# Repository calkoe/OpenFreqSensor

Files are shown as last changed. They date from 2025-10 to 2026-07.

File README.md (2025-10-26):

# ⚡ OpenFrequencySensor - Open Source Power Grid Frequency Monitor

A low-cost, high-precision power grid frequency monitoring solution for the European power grid. Monitor grid stability with ±0.002Hz precision and get instant alerts for frequency deviations.

#### Features

- 📊 Real-time frequency monitoring (±0.002Hz precision)
- 🔔 Local alerts via LCD display and buzzer
- 📡 MQTT data transmission
- 📱 20x4 LCD interface with button controls
- 🔋 Offline operation capability
- 📦 3D-printable case included

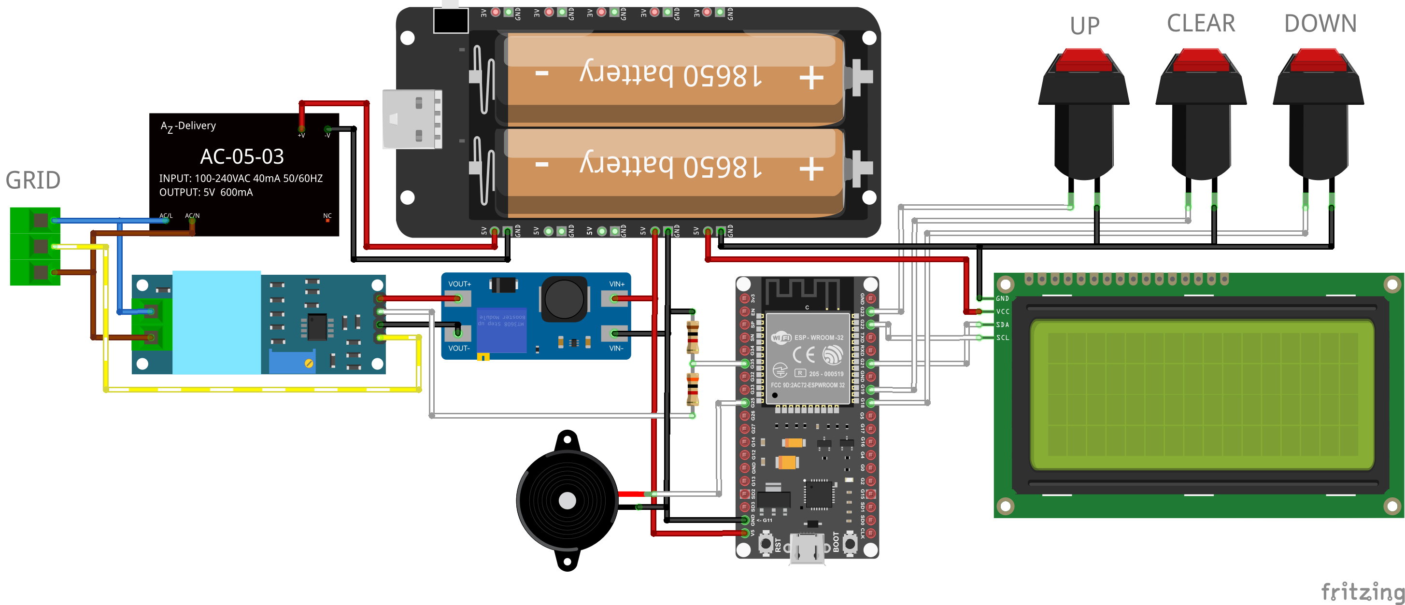
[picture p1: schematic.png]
Schematic


## Why Monitor Grid Frequency?

Frequency is the heartbeat of the electrical grid - it reflects the instantaneous balance between electricity generation and consumption across the entire Continental European network. When this balance shifts, frequency changes reveal:

- **Supply-Demand Imbalances**: Frequency drops when demand exceeds generation, rises when generation exceeds demand

Every frequency change tells a story about grid operations:

- **Slow Drifts (minutes)**: Indicate systematic generation-load imbalances, economic dispatch changes
- **Fast Changes (seconds)**: Reveal sudden events like generator trips, large load connections/disconnections
- **Oscillations**: Show control system interactions, potential stability issues
- **Rate of Change**: Indicates how rapidly the system is losing or gaining energy

By monitoring frequency, you gain insight into:

- **Early Warning System**: Detect grid disturbances before they escalate to blackouts
- **Load-Generation Balance**: Understand real-time supply and demand dynamics

Critical Thresholds (ENTSO-E Standards)

| Threshold | Value | Description |
| --- | --- | --- |
| Standard Frequency Range | 49.95 - 50.05 Hz | Normal operating range |
| Alert Range | 49.8 - 50.2 Hz | Deviation monitoring required |
| Level 1 Emergency | 49.2 - 50.8 Hz | Emergency state |
| Level 2 Emergency | 47.5 - 51.5 Hz | Blackout risk |
| Rate of Change (RoCoF) | > ±0.5 Hz/s | Dynamic stability threshold |

Source: ENTSO-E Operation Handbook, Policy 1: Load-Frequency Control and Performance, Section A-S1: Standard Frequency Range Parameters. These are the official thresholds for the Continental Europe Synchronous Area.

## Live Demo and Data Analysis

View real-time frequency data from this sensor: [Live Dashboard](https://grafana.fastalert.nrw/public-dashboards/0828674a5dd54280aab2e0723ffaba71?orgId=3&refresh=1s)

For comprehensive grid analysis and historical data, visit [Energy-Charts](https://www.energy-charts.info/index.html?l=de&c=DE), maintained by Fraunhofer ISE.

## Getting Started

#### Hardware Requirements

- ESP32 development board [Link](https://www.az-delivery.de/en/products/esp32-developmentboard)
- 20x4 LCD display (I2C) [Link](https://www.az-delivery.de/en/products/hd44780-2004-lcd-display-bundle-4x20-zeichen-mit-i2c-schnittstelle)
- Push buttons (3x) [Link](https://www.amazon.de/-/en/pieces-momentary-pressure-lockless-dashboard/dp/B0DJNWWRSL)
- Buzzer [Link](https://www.az-delivery.de/products/buzzer-modul-passiv)
- ZMPT101B Active Single Phase Voltage Transformer [LINK](https://www.amazon.de/ANGEEK-ZMPT101B-Voltage-Transformer-Arduino/dp/B07ZDJS7CD)
- 5V USV Module [LINK](https://de.aliexpress.com/item/1005009864874228.html)
- HDR-15 Power Supply [LINK](https://www.amazon.de/-/en/Amazon-Parent-MeanWell-Series-HDR-15/dp/B06XWQSJGW)

##### 3D Printable Case

The device housing consists of three parts that can be 3D printed:

- [Part 1 (Base)](Part1.stl)
- [Part 2 (Display Frame)](Part2.stl)
- [Part 3 (Cover)](Part3.stl)

Print Settings:

- Material: PETG or ABS recommended (better heat resistance than PLA)
- Layer Height: 0.2mm
- Infill: 25%

#### Software

1. **Hardware Setup**

   - Follow the provided schematic
   - Print the case using provided STL file
   - Connect components according to pin configuration:
     ```
     ADC Input: GPIO34
     LCD: SDA -> GPIO21, SCL -> GPIO22
     Buttons: Up -> GPIO23, Down -> GPIO19, Mute -> GPIO18
     Buzzer: GPIO25
     ```

2. **Software Setup**

   ```bash
   # Clone the repository
   git clone https://github.com/calkoe/OpenFreqSensor

   # Install PlatformIO
   # Open project in PlatformIO
   # Configure wifi settings in config.h
   # Build and upload
   ```

3. **Configuration**

   - Copy `include/config.template.h` to `include/config.h`
   - Edit `config.h` with your settings:

     ```cpp
     // Network settings
     #define WIFI_SSID "your_ssid"
     #define WIFI_PASSWORD "your_password"
     #define MQTT_SERVER "your_mqtt_server"
     #define MQTT_USERNAME "your_username"
     #define MQTT_PASSWORD "your_password"

     // Device identification
     #define SENSOR_ID "freqsensor/your_id"
     ```

   - The template file contains all available configuration options
   - `config.h` is ignored by git to keep your private settings secure

#### MQTT Data Format

The sensor publishes JSON messages with the following structure:

```json
{
  "sensorId": "freqsensor/koecher1", // Unique sensor identifier
  "time": 1761407894423, // UNIX timestamp in milliseconds
  "freq": 49.964, // Current grid frequency in Hz
  "amp": 167844.8, // Signal amplitude (ADC units)
  "quality": 0.012, // Measurement quality (lower is better)
  "alert": false, // Whether frequency exceeds thresholds
  "alertType": "none", // Type of alert if triggered
  "deviation": 0.036, // Deviation from 50 Hz
  "ramp": 0.002990723, // Rate of change in Hz/s
  "analyzingDelay": 250, // Processing time in ms
  "freeHeap": 111228, // Available ESP32 memory in bytes
  "heapUsage": 65.4, // Memory usage percentage
  "cpuFreq": 240, // CPU frequency in MHz
  "wifiRSSI": -60 // WiFi signal strength in dBm
}
```

#### Technical Details

- Sampling Rate: 512 Hz
- FFT Analysis Size: 512 samples
- Gaussian interpolation for high precision
- Ring buffer size: 4096 samples
- Analysis interval: 250ms

## Example Build

#### Completed Device

- Assembled with ESP32 and components
- 3D printed case
- LCD display showing real-time frequency readings

#### Testing Results

- Frequency accuracy: ±0.002Hz verified against reference meter
- Response time: <250ms for frequency changes
- MQTT connectivity: Stable data transmission
- Battery backup: 4+ hours operation during power outages

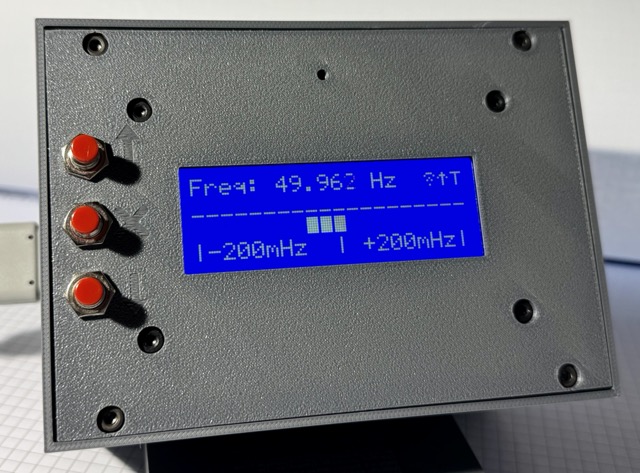
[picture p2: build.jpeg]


## Contributing

Pull requests are welcome. For major changes, please open an issue first to discuss what you would like to change.

## License

[MIT](LICENSE)

## Disclaimer and Safety Warning ⚠️

#### Legal Disclaimer

This project is provided "AS IS", without warranty of any kind, express or implied. By using this project, you agree that:

- The authors and contributors are NOT LIABLE for any damages or injuries arising from the use of this project
- This project is for EDUCATIONAL AND RESEARCH PURPOSES ONLY
- Any use of this project is AT YOUR OWN RISK
- The accuracy and reliability of measurements cannot be guaranteed
- This is NOT a certified measurement device

#### Safety Warning ⚡

This device:

- Connects to LETHAL MAINS VOLTAGE (230V AC)
- Should ONLY be built and installed by QUALIFIED PERSONNEL
- Requires proper electrical isolation and safety measures
- Must be properly enclosed in an insulated case
- Should never be operated without proper safety barriers

DO NOT attempt to build or use this device unless you:

- Are a qualified electrician or electrical engineer
- Fully understand the risks of working with mains voltage
- Know how to properly isolate high-voltage circuits
- Can implement proper safety measures

IMPROPER USE CAN RESULT IN:

- Electric shock
- Death
- Fire
- Property damage

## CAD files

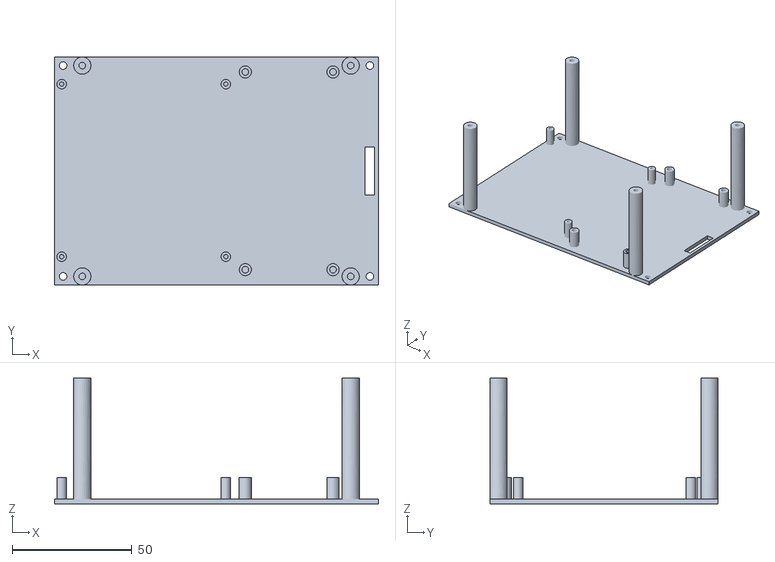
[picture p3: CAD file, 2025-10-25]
Part2.stl
135.2 x 95.2 x 52.5

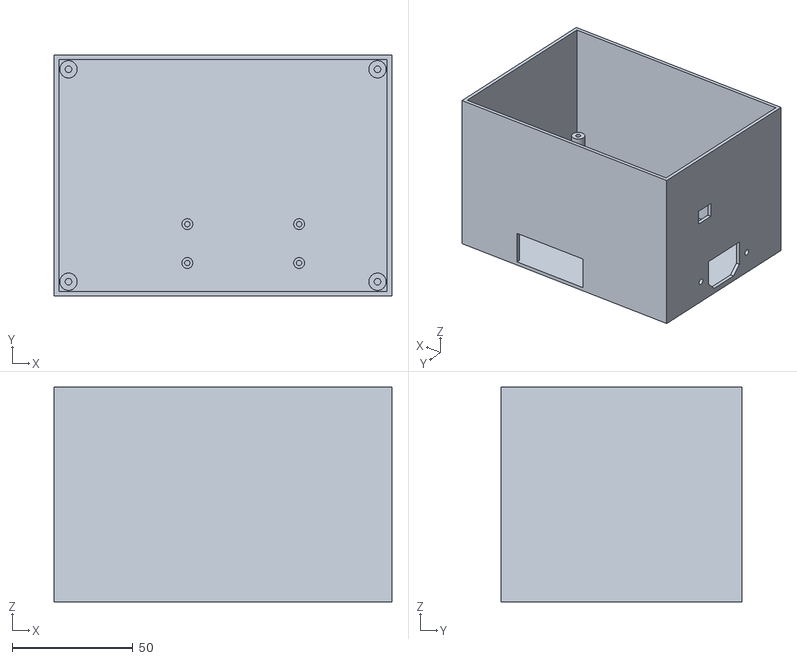
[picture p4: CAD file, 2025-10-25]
Part1.stl
140.0 x 100.0 x 89.0

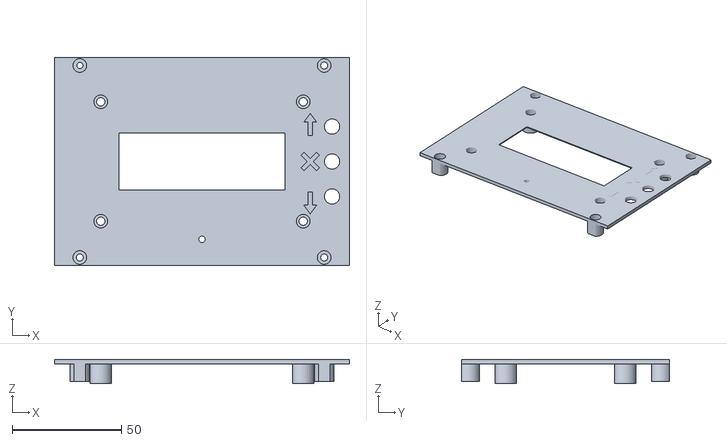
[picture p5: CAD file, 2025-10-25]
Part3.stl
135.2 x 95.2 x 11.0

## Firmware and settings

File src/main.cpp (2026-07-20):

#include "main.h"
#include <esp_task_wdt.h>

// Global variables initialization
hw_timer_t *timer = NULL;
Networking *networking = nullptr;
FrequencyAnalyzer *analyzer = nullptr;
FrequencyInterpreter *interpreter = nullptr;
FrequencyTransmitter *transmitter = nullptr;
DisplayHandler *display = nullptr;

// ISR must stay minimal: analogRead() & friends are not ISR-safe (flash
// resident, take locks) and crash/hang when WiFi does flash writes.
// The actual sampling happens in the analyzer's high-priority task.
void IRAM_ATTR onTimer(){
    analyzer->notifySampleFromISR();
}

void setup_timer(){

    // Configure timer for stable 512Hz sampling with larger prescaler
    uint32_t apb_freq = getApbFrequency();
    uint32_t prescaler = 2;
    uint32_t timer_divider = apb_freq / (prescaler * SAMPLING_FREQUENCY);

    timer = timerBegin(0, prescaler, true);
    timerAttachInterrupt(timer, &onTimer, true);
    timerAlarmWrite(timer, timer_divider, true);
    timerAlarmEnable(timer);

    Serial.printf("APB Freq: %lu Hz, Timer Divider: %lu, Actual sampling rate: %.2f Hz\n",
                  apb_freq, timer_divider, (float)apb_freq / (prescaler * timer_divider));

}

void setup(){

    // Set CPU frequency
    setCpuFrequencyMhz(CPU_FREQUENCY_MHZ);
    Serial.begin(115200);

    // Watchdog: reboot instead of hanging forever if loop() ever stalls
    // (e.g. network stack wedged). Timeout must exceed the worst-case
    // blocking TLS connect (2 x NET_TIMEOUT_S).
    esp_task_wdt_init(WDT_TIMEOUT_S, true);
    esp_task_wdt_add(NULL);

    // Initialize Display
    display = new DisplayHandler();
    display->begin();

    // Initialize networking
    networking = new Networking();
    networking->begin();

    // Initialize frequency analysis components
    analyzer = new FrequencyAnalyzer();
    interpreter = new FrequencyInterpreter();
    transmitter = new FrequencyTransmitter(networking->getMqttClient());

    // Start sampling task, then the timer that triggers it
    pinMode(ADC_PIN,INPUT);
    analyzer->beginSampling();
    setup_timer();

}

void loop(){

      // Feed the watchdog
      esp_task_wdt_reset();

      // Analyze Data
      FrequencyAnalysis frequencyAnalysis{0};
      if(analyzer->getNextSliceAnalysis(&frequencyAnalysis)){
        FrequencyAlert alert = interpreter->interpret(frequencyAnalysis);
        display->updateAnalysis(frequencyAnalysis);
        if(alert.valid){

            // Update display and handle alerts
            if (alert.hasAlert) display->addAlert(alert);

            // Transmit the results via MQTT
            transmitter->transmit(alert);

        }

        // Debug information
        Serial.print("Freq: ");
        Serial.print(frequencyAnalysis.frequency, 3);
        Serial.print(", Ampl: ");
        Serial.print(frequencyAnalysis.amplitude);
        Serial.print(", Quality: ");
        Serial.println(frequencyAnalysis.quality, 3);
      };
      
      // Networking Data
      networking->loop();

      // Display Loop
      display->loop();

      // Add small delay to prevent task hogging CPU
      vTaskDelay(pdMS_TO_TICKS(10)); 

}

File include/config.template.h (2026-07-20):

#ifndef CONFIG_H
#define CONFIG_H

// Helper macros to check if config is set
// Validates that configuration values have been properly set and are not default placeholders
#define IS_PLACEHOLDER(str) ((strcmp(str, "your_ssid") == 0) || \
                           (strcmp(str, "your_password") == 0) || \
                           (strcmp(str, "your_mqtt_server") == 0) || \
                           (strcmp(str, "your_username") == 0) || \
                           (strcmp(str, "your_id") == 0))

// Device Configuration
#define SENSOR_ID "freqsensor/your_id"    // Unique identifier for this sensor instance in the MQTT network

// Network Configuration
// WiFi and MQTT settings for data transmission and remote monitoring
#define WIFI_SSID "your_ssid"             // Your WiFi network name
#define WIFI_PASSWORD "your_password"      // Your WiFi password
#define MQTT_TOPIC "public/freqsensor/your_id"  // MQTT topic for publishing frequency data
#define MQTT_SERVER "your_mqtt_server"     // MQTT broker address
#define MQTT_PORT 1883                     // Standard MQTT port (1883=unencrypted, 8883=encrypted)
#define MQTT_USERNAME "your_username"      // MQTT broker authentication username
#define MQTT_PASSWORD "your_password"      // MQTT broker authentication password

// Configuration state flags
// Runtime checks to ensure proper configuration
#define WIFI_CONFIGURED (!IS_PLACEHOLDER(WIFI_SSID) && !IS_PLACEHOLDER(WIFI_PASSWORD))
#define MQTT_CONFIGURED (!IS_PLACEHOLDER(MQTT_SERVER) && !IS_PLACEHOLDER(MQTT_USERNAME))

// Connection Handling Configuration
#define NET_STATUS_INTERVAL_MS 5000     // How often WiFi/MQTT/NTP status is checked and shown
#define WIFI_FORCE_RECONNECT_MS 60000   // Force a full WiFi re-association after this long offline
#define MQTT_RETRY_INTERVAL_MS 30000    // Minimum time between (blocking) MQTT/TLS connect attempts
#define NET_TIMEOUT_S 10                // Socket / TLS handshake timeout in seconds
#define WDT_TIMEOUT_S 60                // Task watchdog: reboot if loop() stalls this long

// NTP Configuration
// Time synchronization settings for accurate timestamping
#define NTP_SERVER "pool.ntp.org"          // NTP server pool for time synchronization
#define TIME_ZONE "CET-1CEST,M3.5.0,M10.5.0/3"  // Central European Time with automatic DST

// Hardware Pin Configuration
// ESP32 GPIO assignments for various components
#define ADC_PIN 34           // ADC input for grid voltage measurement (GPIO34 = ADC1_CH6)
#define BUTTON_UP_PIN 23     // Navigation button for menu/value increase
#define BUTTON_DOWN_PIN 19   // Navigation button for menu/value decrease
#define BUTTON_MUTE_PIN 18   // Silence alarm buzzer and acknowledge alerts
#define LCD_I2C_ADDR 0x27    // Default I2C address for PCF8574 LCD backpack
#define LCD_SDA_PIN 21       // I2C data line for LCD communication
#define LCD_SCL_PIN 22       // I2C clock line for LCD communication
#define BUZZER_PIN 25        // Alert buzzer output
#define BUTTON_DEBOUNCE_MS 500  // Button debounce delay to prevent multiple triggers

// Frequency Analysis Configuration
// Signal processing parameters for accurate frequency measurement
#define SAMPLING_FREQUENCY 512    // ADC sampling rate (Hz) - Nyquist frequency > 100Hz
#define RING_BUFFER_SIZE 4096    // Circular buffer for continuous sampling (8 seconds)
#define ANALYSIS_SIZE 512        // FFT window size (1 second of data)
#define ANALYSIS_INTERVAL_MS 250 // Update rate for frequency calculations (4 Hz)
#define AMPLITUDE_THRESHOLD 10000 // Minimum signal strength for valid measurement

// Frequency Interpretation Configuration
// All thresholds according to ENTSO-E Operation Handbook, Policy 1
#define TARGET_FREQUENCY 50.000f          // Nominal frequency of the Continental European power grid (Hz)
#define STANDARD_RANGE_THRESHOLD 0.050f   // Normal operation range threshold (±50mHz). If exceeded, monitoring required
#define ALERT_RANGE_THRESHOLD 0.200f      // Alert state threshold (±200mHz). Triggers system operator awareness
#define LEVEL1_EMERGENCY_THRESHOLD 0.200f // Level 1 Emergency threshold (±800mHz). System stressed, corrective actions needed
#define LEVEL2_EMERGENCY_THRESHOLD 0.800f // Level 2 Emergency threshold (±2500mHz). High risk of grid collapse
#define ROCOF_THRESHOLD 0.500f           // Rate of Change of Frequency threshold (±500mHz/s). Indicates dynamic stability issues
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

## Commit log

2025-10-25 Initial commit: FreqSensor - Open Source Power Grid Frequency Monitor
    [schematic.fzz]
2025-10-25 Refactor code structure for improved readability and maintainability
    [Part1.stl, Part2.stl, Part3.stl]
2025-10-26 Refactor frequency analysis and interpreter for improved performance and accuracy; update timer configuration and display handling
2026-07-20 Add concept for true 4 Hz frequency measurement using phase difference method
